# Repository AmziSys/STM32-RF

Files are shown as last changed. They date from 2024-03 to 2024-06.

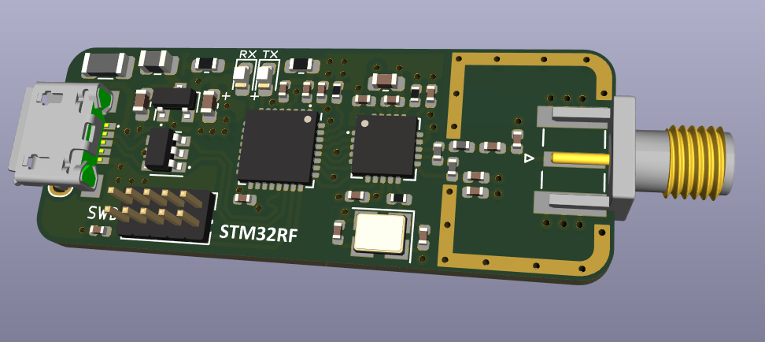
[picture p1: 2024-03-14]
STM32RF-1.PNG

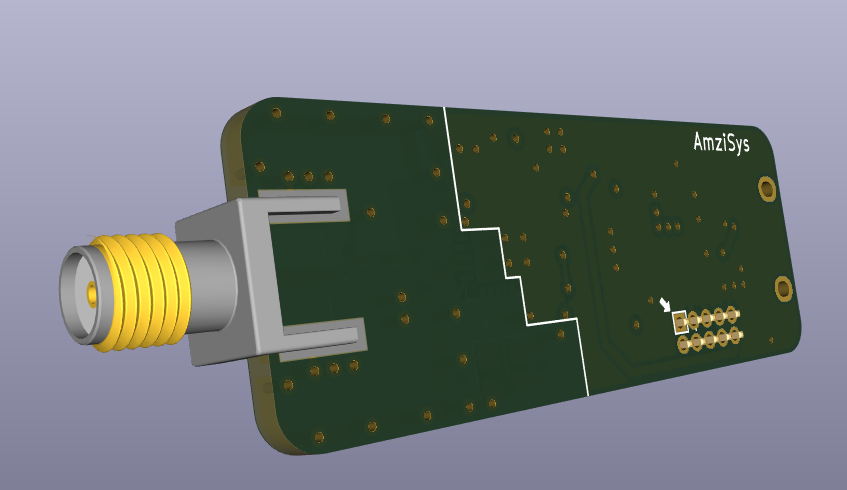
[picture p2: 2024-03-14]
STM32RF-2.PNG

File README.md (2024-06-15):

# STM32-RF
---------------------------------- STM32RF board ----------------------------------------

* Intro:
  The idea of the board is to be used in a system where data is sent over the air. The data is received by the antenna and processed in the microcontroller then sent out to a host computer via the USB interface.

* Design:
  The board contains:
  - STM32L432KBU6: STM32 microcontroller
  - nRF24L01P: 2.4GHz RF transceiver suitable for ultra-low power wireless applications (ISM band)
  - Power supply: USB, ESD protection, Fuse, and LDO regulator
  - Antenna interface and its matching circuit
  - R and C

During the design process, the system/board was divided into 3 parts: the RF part (receive data), The microcontroller part (processing data), and the USB part (communicate data with a PC).
In general, anything RF needs to be in 4 layers. So, the front layer will be used for signals, the inner-cooper-layer 1 will be ground (GND), the Inner-cooper-layer 2 will be power (or 3.3V), and the bottom copper layer will be used for signals.

* The design was made in Kicad 6

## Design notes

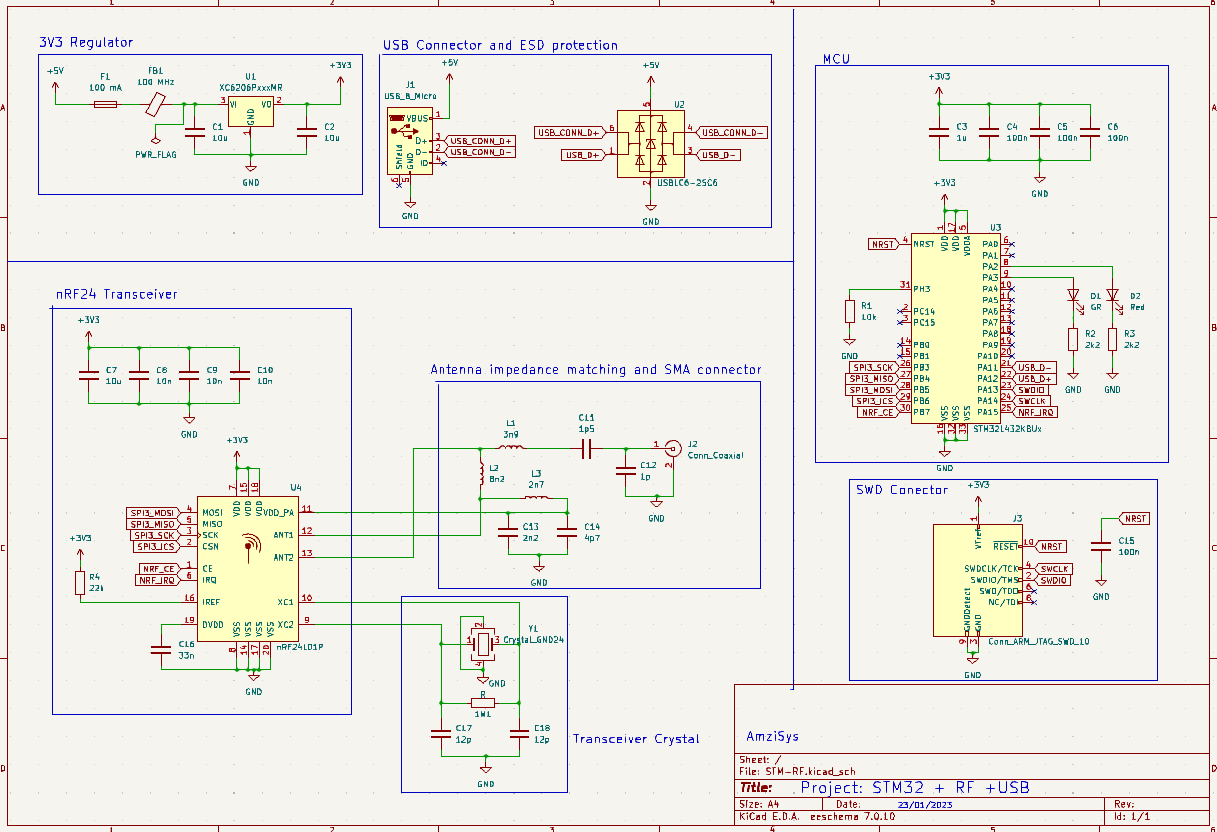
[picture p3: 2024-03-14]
STM32RF-schematic.PNG

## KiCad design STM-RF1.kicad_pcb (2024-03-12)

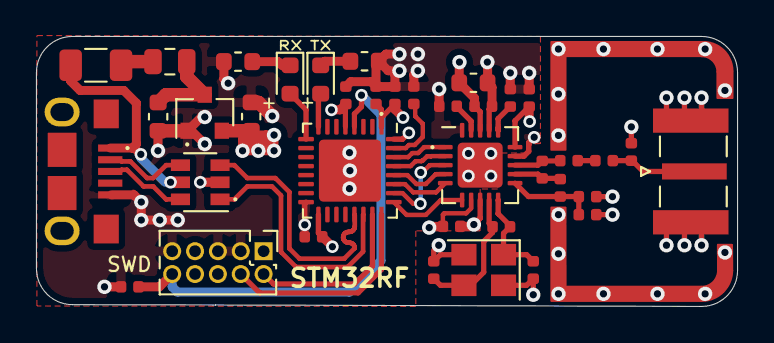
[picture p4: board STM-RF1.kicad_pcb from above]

Board: 4 copper layers, 39.0 x 15.0 mm, 38 parts (0 on the bottom side), 32 nets.

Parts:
C1, C2, C8: 10u; C_0603_1608Metric
C3, C5, C6, C7: 100n; C_0402_1005Metric
C4: 1u; C_0402_1005Metric
C9, C10, C11: 10n; C_0402_1005Metric
C12: 33n; C_0402_1005Metric
C13, C14: 12p; C_0402_1005Metric
C15: 1p5; C_0402_1005Metric
C16: 1p; C_0402_1005Metric
C17: 2n2; C_0402_1005Metric
C18: 4p7; C_0402_1005Metric
D1: GR; LED_0603_1608Metric
D2: YE; LED_0603_1608Metric
F1: 100mA; Fuse_1206_3216Metric
FB1: 100 @ 100MHz; L_0805_2012Metric
J1: USB_B_Micro; 101181930001LF
J2: SMA; SMA_Samtec_SMA-J-P-X-ST-EM1_EdgeMount
J3: ARM 10pin; PinHeader_2x05_P1.27mm_Vertical
L1: 3n9; L_0402_1005Metric
L2: 8n2; L_0402_1005Metric
L3: 2n7; L_0402_1005Metric
R1: 2k2; R_0402_1005Metric
R2, R3: 2k2; R_0603_1608Metric
R4: 22k; R_0402_1005Metric
R5: 1M; R_0402_1005Metric
U1: XC6206P332MR; SOT-23
U2: USBLC6-2SC6; SOT-23-6
U3: STM32L432KBU6; QFN-32-1EP_5x5mm_P0.5mm_EP3.45x3.45mm
U4: nRF24L01P; QFN-20-1EP_4x4mm_P0.5mm_EP2.5x2.5mm
Y1: 16MHz; Crystal_SMD_3225-4Pin_3.2x2.5mm

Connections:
+3V3: C2.1, C4.1, C5.1, C6.1, C7.1, C8.1, C9.1, C10.1, C11.1, J3.1, U1.2, U3.1, U3.5, U3.17, U4.7, U4.15, U4.18
+5V: F1.2, J1.1, U2.5
GND: C1.2, C2.2, C3.2, C4.2, C5.2, C6.2, C7.2, C8.2, C9.2, C10.2, C11.2, C12.2, C13.2, C14.2, C16.1, C17.1, C18.1, J1.5, J2.2, J3.3, J3.5, J3.9, R1.2, R2.2, R3.2, R4.2, U1.1, U2.2, U3.16, U3.32, U3.33, U4.8, U4.14, U4.17, U4.20, U4.21, Y1.2, Y1.4
NRF_ANT1: L2.2, L3.2, U4.12
NRF_ANT2: L1.1, L2.1, U4.13
NRF_CE: U3.30, U4.1
NRF_IRQ: U3.25, U4.6
NRF_VDD_PA: C17.2, C18.2, L3.1, U4.11
NRF_XC1: C13.1, R5.2, U4.10, Y1.1
NRF_XC2: C14.1, R5.1, U4.9, Y1.3
NRST: C3.1, J3.10, U3.4
unnamed: C1.1, FB1.1, U1.3
unnamed: C12.1, U4.19
unnamed: C15.1, C16.2, J2.1
unnamed: C15.2, L1.2
unnamed: D1.1, R2.1
unnamed: D1.2, U3.9
unnamed: D2.1, R3.1
unnamed: D2.2, U3.8
unnamed: F1.1, FB1.2
unnamed: R1.1, U3.31
unnamed: R4.1, U4.16
SPI3_!CS: U3.29, U4.2
SPI3_MISO: U3.27, U4.5
SPI3_MOSI: U3.28, U4.4
SPI3_SCK: U3.26, U4.3
SWCLK: J3.4, U3.24
SWDIO: J3.2, U3.23
USB_CONN_D+: J1.3, U2.6
USB_CONN_D-: J1.2, U2.4
USB_D+: U2.1, U3.22
USB_D-: U2.3, U3.21
